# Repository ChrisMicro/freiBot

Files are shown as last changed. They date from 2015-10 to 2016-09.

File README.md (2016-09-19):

# freiBot
The freiBot is a very low cost two wheel robot.
The design goal is a robot which is
- easy and fast to build ( 6 hours )
- easy to program ( using an ARDUINO NANO )
- low circuit cost
- usefull for workshops

Here you can see the pictures:

http://roboterclub-freiburg.de/projekte/freibot

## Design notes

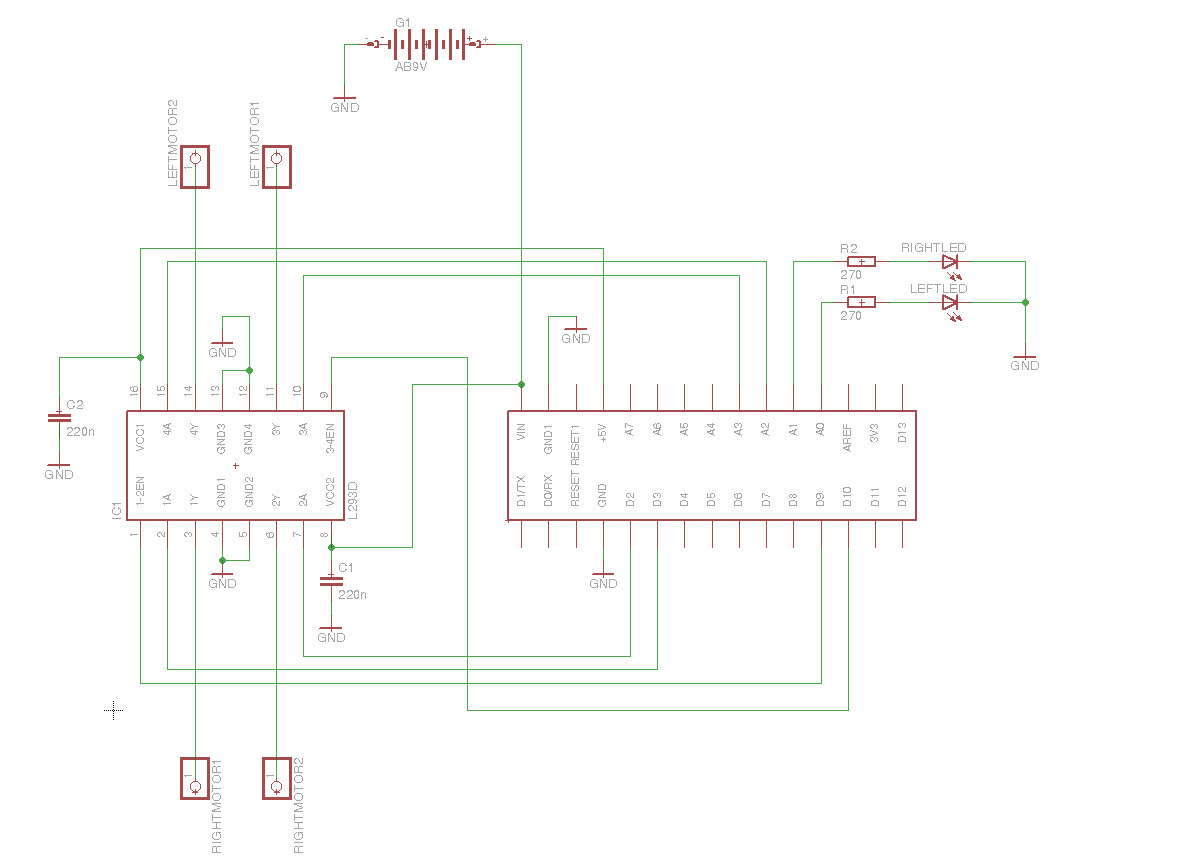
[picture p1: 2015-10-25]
freiBot_schnematic.jpg

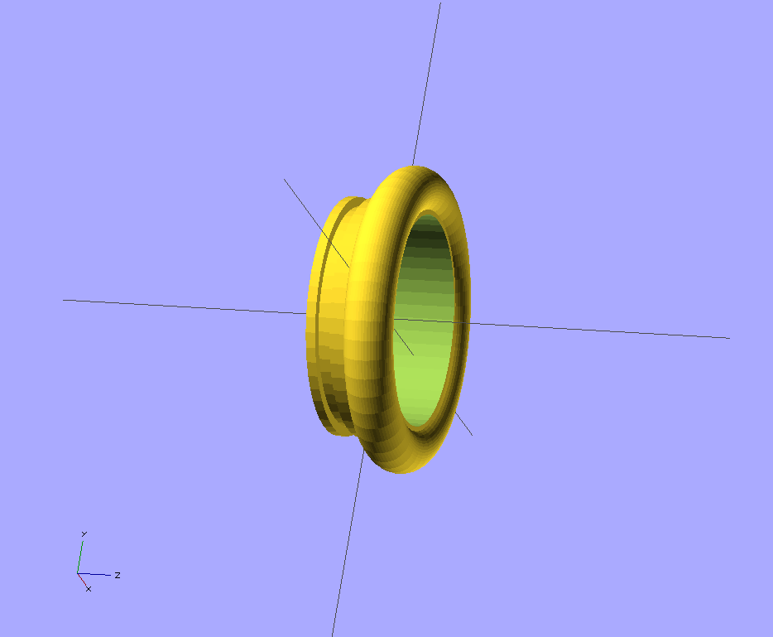
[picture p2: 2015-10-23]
cad/openscad/chFreiBotWheel.png

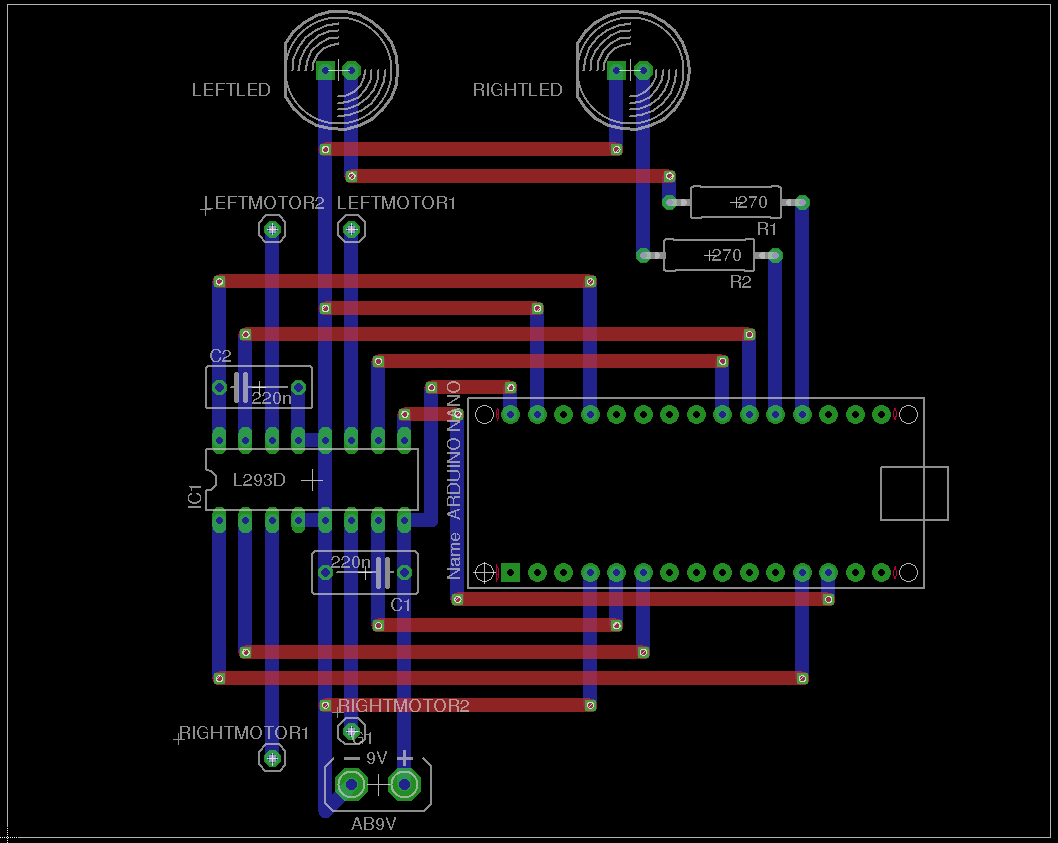
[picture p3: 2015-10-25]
eagle/StreifenrasterLayoutFreiBot20151025_1.png

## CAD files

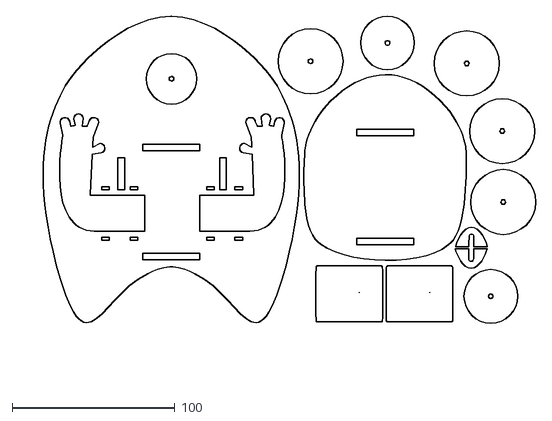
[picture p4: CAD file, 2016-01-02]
cad/freibot_grundplatte_4mm_lurch.dxf
319.6 x 224.4

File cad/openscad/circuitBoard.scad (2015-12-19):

boardLength=75;
boardHeight=1.5;
boardWidth=100;

color("silver") translate([0,0,basePlateOffset]) 		
	cube(size = [basePlateLength,basePlateWidth,basePlateHeight], center = true);

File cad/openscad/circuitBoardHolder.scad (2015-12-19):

/*
	circuit board holder

	2015 by ChrisMicro

*/

manuFactoringOffset = 1; // tollarance for colling down the PLA

// outer dimensions
frameLength = 120;
frameWidth  = 95;
frameHeight = 3;

// board dimensions
boardLength = manuFactoringOffset + 100;
boardWidth  = manuFactoringOffset + 75 ;
boardHeight = manuFactoringOffset + 1.5;

boardAuflageBreite = 3;

circuitBoardHolder();

module circuitBoardHolder()
{
	difference()
	{
		// frame
		cube([frameLength,frameWidth,frameHeight]);
	
		// hole 
		translate([(frameLength-boardLength)/2+boardAuflageBreite,(frameWidth-boardWidth)/2+boardAuflageBreite,0])
			cube([boardLength-boardAuflageBreite*2,boardWidth-boardAuflageBreite*2,frameHeight]);

		// board
		translate([(frameLength-boardLength)/2,(frameWidth-boardWidth)/2,frameHeight-boardHeight])
			cube([boardLength,boardWidth,boardHeight]);
	}
}	

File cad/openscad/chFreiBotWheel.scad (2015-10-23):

/*
	freiBot Pneu
	robot wheel for freiBot
	2015 by stochri
*/

$fn = 50;

ballBearingDiameter=22;
wheelDiameter=32;
nutBreite=1.5;
nutTiefe=2;
nutEntfernung=2;

schlauchdicke=wheelDiameter-ballBearingDiameter;

d1=1;
d2=1;

// reifen 
translate([0,0,schlauchdicke/4])
	torus(ballBearingDiameter,wheelDiameter);

// auffüllung rad reifen
translate([0,0,0])
	ring(schlauchdicke/4+d1,ballBearingDiameter,wheelDiameter-schlauchdicke/2);

// innenring der nut
translate([0,0,-nutEntfernung])
	ring(schlauchdicke/2+d1,ballBearingDiameter,ballBearingDiameter+d2+nutTiefe);

// nut für gummiantrieb
translate([0,0,-nutEntfernung-nutBreite])
	ring(nutBreite,ballBearingDiameter,ballBearingDiameter+d2);

// aussenring der nut
translate([0,0,-nutEntfernung-nutBreite-d1])
	ring(d1,ballBearingDiameter,ballBearingDiameter+d2+nutTiefe);


module ring(thickness,innerDiameter,outerDiameter)
{
	difference()
	{
		cylinder(thickness,outerDiameter/2,outerDiameter/2);
		cylinder(thickness,innerDiameter/2,innerDiameter/2);
	}	
}

module torus(inner,outer)
{
	rotate_extrude(convexity = 10)
	translate([outer/2-(outer/2-inner/2)/2, 0, 0])
		circle(r = (outer/2-inner/2)/2); 
}

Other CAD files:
cad/openscad/freiBotWheelDualRubberBand.scad
cad/openscad/BatteryHolder9V.scad
cad/openscad/JohnsonNF243G-20242.scad
cad/openscad/Main_baseplate.scad
cad/openscad/axis.scad
cad/openscad/axisBearings.scad
cad/openscad/axisBearingsDual.scad
cad/openscad/ballBearing.scad
cad/openscad/baseplate.scad
cad/openscad/freiBotWheelRubberBand.scad
cad/openscad/freiBotWheelRubberWasher.scad
cad/openscad/freiBot_pneu.scad
cad/openscad/lgo_holePlate.scad
cad/openscad/motorHolder.scad
cad/openscad/motorHolderWithOutBasePlate.scad
cad/openscad/motorHolderlgo.scad
cad/openscad/pulley.scad
cad/openscad/switchMount.scad
cad/openscad/washer.scad

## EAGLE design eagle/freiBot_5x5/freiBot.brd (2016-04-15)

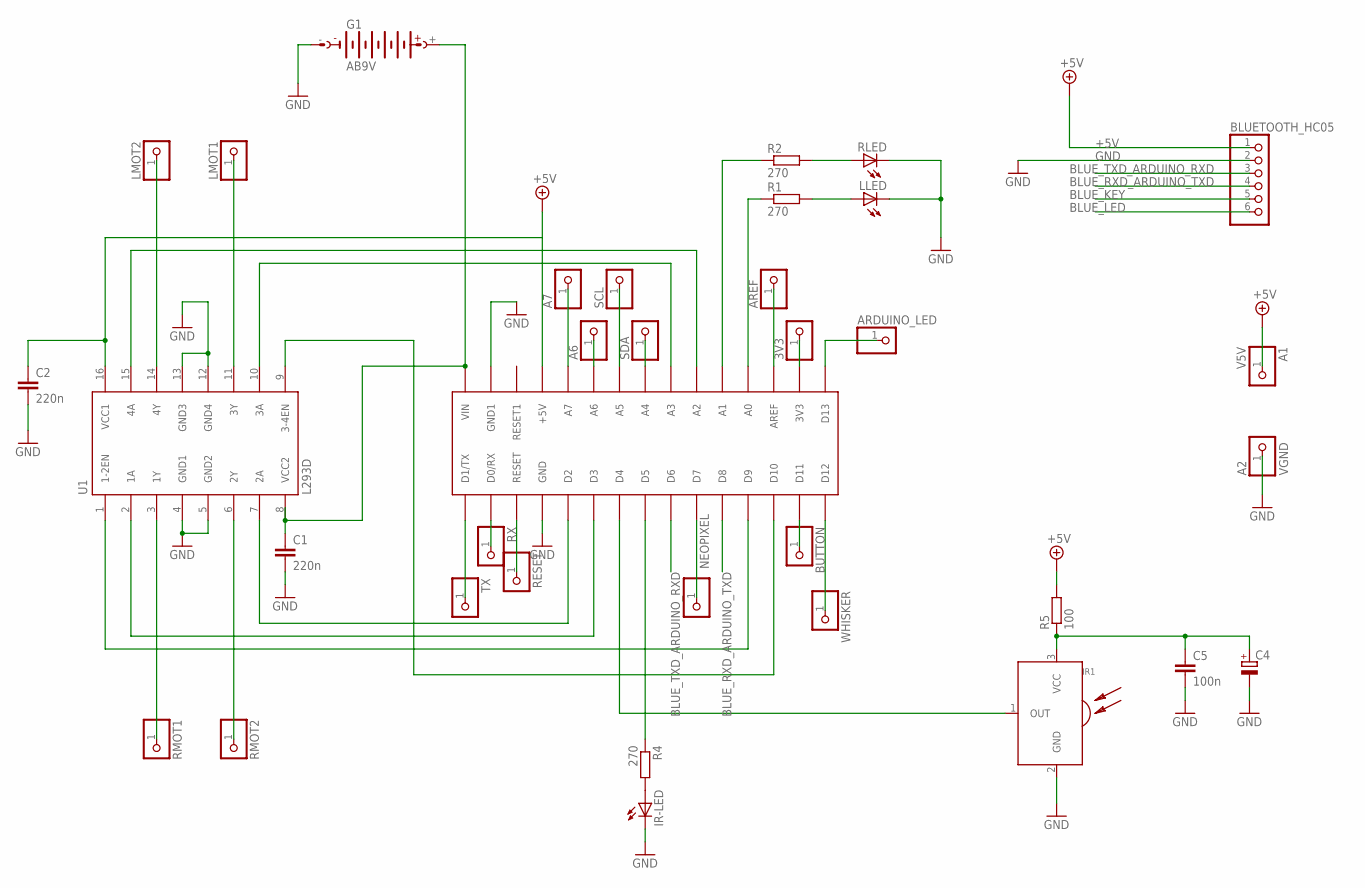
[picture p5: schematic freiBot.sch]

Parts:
3V3: PINHD-1X1; 1X01
A1: V5V; 1X01
A2: VGND; 1X01
A6, A7: PINHD-1X1; 1X01
ARDUINO_LED: PINHD-1X1; 1X01
AREF: PINHD-1X1; 1X01
BLUETOOTH_HC05: PINHD-1X6; 1X06
BUTTON: PINHD-1X1; 1X01
C1, C2: 220n; C075-042X103
C4: CPOL-EUE5-8.5; E5-8,5
C5: 100n; C050-025X075
G1: AB9V
IR1: SFH5110; SFH511*
IR-LED: LED5MM
LLED: LED10MM
LMOT1, LMOT2: PINHD-1X1; 1X01
NEOPIXEL: PINHD-1X1; 1X01
R1, R2, R4: 270; 0309/12
R5: 100; 0309/10
RESET: PINHD-1X1; 1X01
RLED: LED10MM
RMOT1, RMOT2: PINHD-1X1; 1X01
RX: PINHD-1X1; 1X01
SCL: PINHD-1X1; 1X01
SDA: PINHD-1X1; 1X01
TX: PINHD-1X1; 1X01
U1: L293D; DIL16
U2: ARDUINONANO; PDIP-32
WHISKER: PINHD-1X1; 1X01

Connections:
+5V: A1.1, BLUETOOTH_HC05.1, C2.1, R5.2, U1.16 (VCC1), U2.+5V
BLUE_KEY: BLUETOOTH_HC05.5
BLUE_LED: BLUETOOTH_HC05.6
BLUE_RXD_ARDUINO_TXD: BLUETOOTH_HC05.4, U2.D8
BLUE_TXD_ARDUINO_RXD: BLUETOOTH_HC05.3, U2.D6
GND: A2.1, BLUETOOTH_HC05.2, C1.2, C2.2, C4.-, C5.2, G1.-, IR1.2 (GND), IR-LED.K (C), LLED.K (C), RLED.K (C), U1.4 (GND1), U1.5 (GND2), U1.12 (GND4), U1.13 (GND3), U2.GND, U2.GND1
unnamed: U1.7 (2A), U2.D2
unnamed: U1.2 (1A), U2.D3
unnamed: U1.1 (1-2EN), U2.D9
unnamed: RMOT1.1, U1.3 (1Y)
unnamed: U1.9 (3-4EN), U2.D10
unnamed: U1.10 (3A), U2.A3
unnamed: U1.15 (4A), U2.A2
unnamed: RMOT2.1, U1.6 (2Y)
unnamed: LMOT1.1, U1.11 (3Y)
unnamed: LMOT2.1, U1.14 (4Y)
unnamed: C1.1, G1.+, U1.8 (VCC2), U2.VIN
unnamed: IR-LED.A, R4.2
unnamed: R1.1, U2.A0
unnamed: R2.1, U2.A1
unnamed: R2.2, RLED.A
unnamed: LLED.A, R1.2
unnamed: SDA.1, U2.A4
unnamed: SCL.1, U2.A5
unnamed: ARDUINO_LED.1, U2.D13
unnamed: U2.D12, WHISKER.1
unnamed: BUTTON.1, U2.D11
unnamed: NEOPIXEL.1, U2.D7
unnamed: IR1.1 (OUT), U2.D4
unnamed: R4.1, U2.D5
unnamed: A6.1, U2.A6
unnamed: 3V3.1, U2.3V3
unnamed: AREF.1, U2.AREF
unnamed: A7.1, U2.A7
unnamed: RESET.1, U2.RESET
unnamed: TX.1, U2.D1/TX
unnamed: RX.1, U2.D0/RX
VCC: C4.+, C5.1, IR1.3 (VCC), R5.1

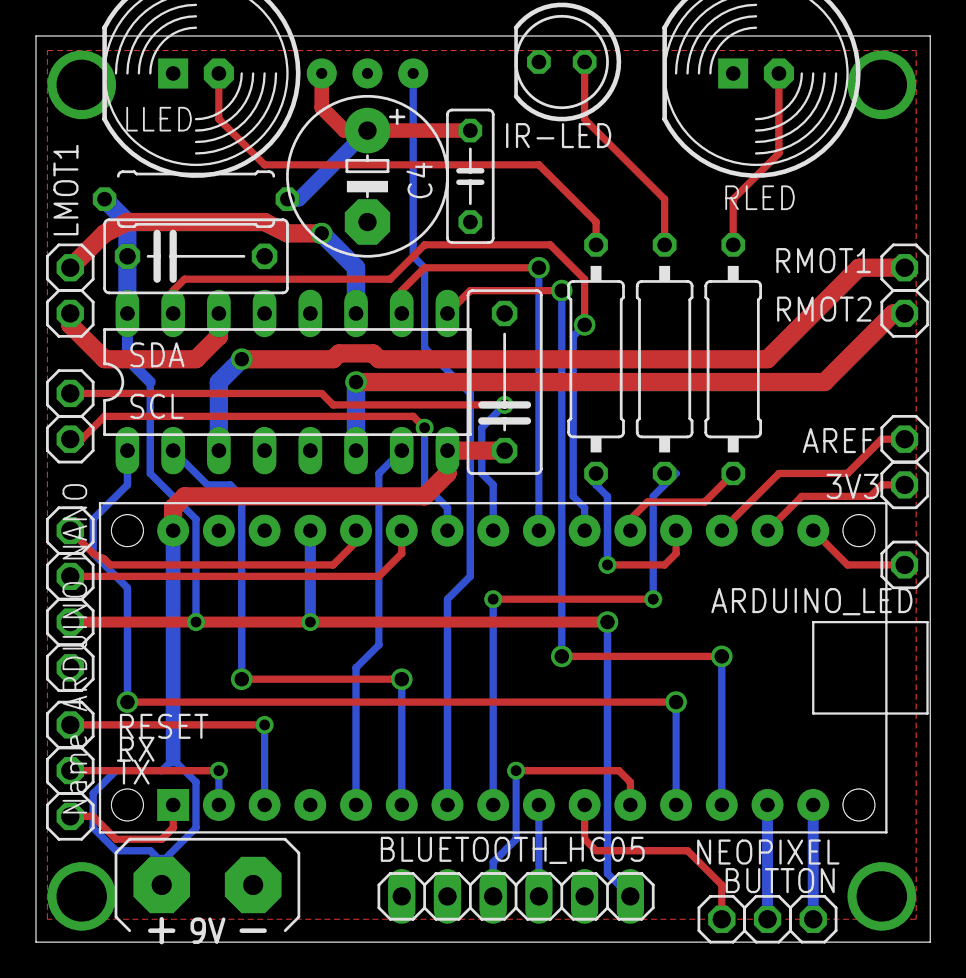
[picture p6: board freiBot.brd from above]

Board: 2 copper layers, 49.7 x 50.3 mm, 35 parts (1 on the bottom side), 36 nets.

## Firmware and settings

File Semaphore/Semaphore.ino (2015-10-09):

#include "freiBot.h"

void setup()
{
  initRobotHardware();
  Serial.begin(9600);
}



uint8_t Semaphore = 0;
// robot state machine with semaphores
void stateMachine()
{
  while (1)
  {
    Serial.print("semaphore: "); Serial.println(Semaphore);

    if ((Semaphore == FREE) || (Semaphore == 1))
    {
      Semaphore = 1;
      if (!digitalRead(BUTTONPIN))
      {
        Semaphore = FREE;
        Serial.println("button pressed");
        digitalWrite(LEDPIN, false);
      }
      else
      {
        digitalWrite(LEDPIN, true);
      }
    }

    if (whiskerTouched())
    {
      MotorDir(RWD, RWD);
      MotorSpeed(255, 100);
      digitalWrite(EYE_LED_LEFT,  0);
      digitalWrite(EYE_LED_RIGHT, 1);
    }

    if ((Semaphore == FREE) || (Semaphore == 2))
    {
      static uint32_t stopTime;
      static uint8_t stateFlag = 0;

      if (stateFlag == 0)
      {
        Semaphore = 2;
        stopTime = millis() + 1000;

        stateFlag = 1;
        MotorDir(FWD, FWD);
        MotorSpeed(255, 255);
        digitalWrite(EYE_LED_LEFT,  1);
        digitalWrite(EYE_LED_RIGHT, 1);
      } else
      {
        if (millis() > stopTime)
        {
          stateFlag = 0;
          Semaphore = FREE;
        }
      }
    }

    if ((Semaphore == FREE) || (Semaphore == 3))
    {
      static uint32_t stopTime;
      static uint8_t stateFlag = 0;

      if (stateFlag == 0)
      {
        Semaphore = 3;
        stopTime = millis() + 1000;
        stateFlag = 1;
        MotorDir(FREE, FREE);
        digitalWrite(EYE_LED_LEFT,  0);
        digitalWrite(EYE_LED_RIGHT, 0);
      } else
      {
        if (millis() > stopTime)
        {
          stateFlag = 0;
          Semaphore = 2;
        }
      }
    }
  }
}

#define MAXSPEED 230
#define MINSPEDD 1
#define SPEEDINCREMENT 10

void lightChaser()
{
  uint8_t leftSpeed = 0;
  uint8_t rightSpeed = 0;
  MotorDir(FWD, FWD);

  while (1)
  {
    MotorSpeed(leftSpeed, rightSpeed);
    if (get_eyeValue(LEFT) > get_eyeValue(RIGHT))
    {
      leftSpeed += SPEEDINCREMENT;
      rightSpeed -= SPEEDINCREMENT;

      setLed(EYE_LED_LEFT, 1);
      setLed(EYE_LED_RIGHT, 0);
      delay(10);
    }
    else
    {
      leftSpeed -= SPEEDINCREMENT;
      rightSpeed += SPEEDINCREMENT;
      setLed(EYE_LED_LEFT, 0);
      setLed(EYE_LED_RIGHT, 1);
      delay(10);
    }
    if (leftSpeed < MINSPEDD)leftSpeed = MINSPEDD;
    if (rightSpeed < MINSPEDD)rightSpeed = MINSPEDD;
    if (leftSpeed > MAXSPEED )leftSpeed = MAXSPEED ;
    if (rightSpeed > MAXSPEED )rightSpeed = MAXSPEED ;
  }
}

void testIrInput()
{
  setLed(EYE_LED_LEFT, 0);
  waitForIrSignal();
  setLed(EYE_LED_LEFT, 1);
  delay(100);
}

void simpleIrMotorControl()
{
  int n, k;
  BEEP;
  waitForIrSignal(); // wait for start signal
  MotorDir(FWD, RWD); // rotate if there is no signal
  MotorSpeed(200, 200);
  for (n = 0; n < 300; n++)
  {
    if(isIrSignal()) // if signal, go forward
    {
      setLed(EYE_LED_LEFT, 1);
      MotorDir(FWD, FWD); 
      delay(500);
      setLed(EYE_LED_LEFT, 0);
    } else 
    {
      MotorDir(FWD, RWD); // rotate if there is no signal
      delay(10);
    }
    if(whiskerTouched())
    {
      chirp();

      MotorSpeed(200, 200);
      // go back
      MotorDir(RWD, RWD); 
      delay(300);
      // turn
      MotorDir(FWD, RWD);
      delay(300);
    }
  }
  MotorDir(FREE, FREE); // turn of motor if there is no signal

}



void loop()
{
  simpleIrMotorControl();
  //testIrInput();
  /*
  lightChaser();
  Serial.print("left: "); Serial.print(get_eyeValue(LEFT));
  Serial.print("  right: "); Serial.println(get_eyeValue(RIGHT));
  delay(10);
  */
}

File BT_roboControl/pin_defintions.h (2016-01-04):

/*************************************************************************************

  GENUBOT 

  robot hardware:

  microcontroller:     Arduino Nano
  motor driver:        L293D
  motors:              Pollin motors 
  wheels:              inline skate ball bearings
  
  sensors:
  - button
  - 1 whisker 
  - 2 LEDs ( used as light sensor )
  - MPU6050 3 axis accelerometer/gyrometer 
  - IR sensor SFH5110

************************************************************************************/

// Arduino Nano pin out and schematic:
// https://www.arduino.cc/en/uploads/Main/ArduinoNanoManual23.pdf

// connecting the ARDUINO Nano and the MPU6050 accelerometer:
// http://shirotsuku.sakura.ne.jp/blog/?p=442
// ( interrupt pin is not connected at the moment to genubot )

// net list:
//===== robot pin name =  ARDUINO pin ===============================================================
#define MOTOR_RIGHT1           2 // dout, L293D pin10, motor driver right side, half bridge 1
#define MOTOR_RIGHT2           3 // dout, L293D pin15, motor driver right side, half bridge 2
#define IR_SENSOR              4  // din , SFH5110 sensor ( signal is active low )
#define BLUE_TXD_ARDUINO_RXD   6  // din, bluetooth hc05 modul 
#define NEOPIXEL_PIN           7  // dout, WS2812 RGB LED controll pin
#define BLUE_RXD_ARDUINO_TXD   8  // dout, bluetooth hc05 modul 
#define ENABLE_RIGHT           9  // dout, L293D pin1, motor driver enable pin for right motor, OC1B used for motor PWM
#define ENABLE_LEFT           10 // dout, L293D pin9, motor driver enable pin for left moter, OC1A used for motor PWM
#define BUTTONPIN             11 // din,  button ( configure with pull up )
#define WHISKERPIN            12 // din,  whisker ( like a button configure with pull up )
#define LEDPIN                13 // dout, ARDUINO NANO LED 

#define EYE_LED_LEFT     A0 // dout,ain, LED or LED as light sensor
#define EYE_LED_RIGHT    A1 // dout,ain, LED or LED as light sensor
#define MOTOR_LEFT2      A2  // dout, L293D pin2, motor driver left side half bridge 2
#define MOTOR_LEFT1      A3  // dout, L293D pin7, motor driver left side half bridge 1

// A2
// A3
#define I2C_SDA_PIN      A4 // I2C SDA, connected to MPU6050
#define I2C_SCL_PIN      A5 // I2C SCL, connected to MPU6050
// A6
// A7

// tbd:
// IR-LED digital out for distance sensor
// digital input for second whisker
// CNY70 line sensor digital out for LED
// CNY70 line sensor digital in for sensor

/*******************************************************************************
*   -c--date---version--nickname--------email---------------------------------
*
*   (c) 2015   V0.1     stochri         christoph(at)roboterclub-freiburg.de
*   (c) ..     V0.2     ...... ........ ( your name ) ........................
*
*******************************************************************************
*   This program is free software; you can redistribute it and/or modify      *
*   it under the terms of the GNU General Public License as published by      *
*   the Free Software Foundation version 2 of the License,                    *
*   If you want to use this software for commercial purposes and you          *
*   don't want to make it open source, please contact the authors for         *
*   licensing.                                                                *
*                                                                             *
*   IF YOU EXTEND THE PROGRAM PLEASE MAINTAIN THE LIST OF AUTHORS             *
*   ( which means adding copyright in the list above )                        *
*                                                                             *
*******************************************************************************/

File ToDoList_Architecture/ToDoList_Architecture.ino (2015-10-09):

/*
 ============================================================================
 Name        : ToDoBuffer_Architecture.c
 Author      : chris
 Version     :
 Copyright   : GPL V3
 Description : ToDo list architecture to control a robot
 ============================================================================
 */
#include "freiBot.h"

#include "ringBuffer.h"

#define TODOLIST_SIZE 100
ToDo_t ToDoList[TODOLIST_SIZE];

ringBuffer_t ToDoBuffer;

void Speed(int16_t a, int16_t b)
{
  MotorSpeed(a, b);
}

void Direction(int16_t a, int16_t b)
{
  MotorDir(a, b);
}

#define FORWARD_LENGTH 2
ToDo_t Forward_List[] =
{
  // turn robot
  {0, Direction, FWD, FWD},
  {500, Speed, 200, 200},
};

#define TURNLEFT_LENGTH 3
ToDo_t TurnLeft_List[] =
{
  // turn robot
  {0, Direction, FWD, RWD},
  {500, Speed, 200, 200},
  // stop motors and wait for two seconds
  {2000, Direction, FREE, FREE}
};

#define BOUNCE_BACK 4
ToDo_t BounceBack_List[] =
{
  // drive back
  {0, Direction, RWD, RWD},
  {300, Speed, 200, 200},
  // turn
  {300, Direction, FWD, RWD},
  // stop motors and wait for 200ms
  {200, Direction, FREE, FREE}
};

void bounceBackBehaviour(int16_t var1, int16_t var2)
{
  ringBufAddInFront(&ToDoBuffer, BounceBack_List, BOUNCE_BACK);
}

void rotateBehaviour(int16_t var1, int16_t var2)
{
  ringBufAddInFront(&ToDoBuffer, TurnLeft_List, TURNLEFT_LENGTH);
}

void forwardBehaviour(int16_t var1, int16_t var2)
{
  ringBufAddInFront(&ToDoBuffer, Forward_List, FORWARD_LENGTH);
}

void setup()
{
  initRobotHardware();
  Serial.begin(9600);
  ringBufferInit( &ToDoBuffer, ToDoList, TODOLIST_SIZE  );

  ringBufAddInFront(&ToDoBuffer, TurnLeft_List, TURNLEFT_LENGTH);
  bounceBackBehaviour(0, 0);
  ringBufAddInFront(&ToDoBuffer, TurnLeft_List, TURNLEFT_LENGTH);
}

void simpleIrMotorControl()
{
  int n, k;
  beep();
  waitForIrSignal(); // wait for start signal
  MotorDir(FWD, RWD); // rotate if there is no signal
  MotorSpeed(200, 200);
  for (n = 0; n < 300; n++)
  {
    if (isIrSignal()) // if signal, go forward
    {
      setLed(EYE_LED_LEFT, 1);
      MotorDir(FWD, FWD);
      delay(500);
      setLed(EYE_LED_LEFT, 0);
    } else
    {
      MotorDir(FWD, RWD); // rotate if there is no signal
      delay(10);
    }
    if (whiskerTouched())
    {
      chirp();

      MotorSpeed(200, 200);
      // go back
      MotorDir(RWD, RWD);
      delay(300);
      // turn
      MotorDir(FWD, RWD);
      delay(300);
    }
  }
  MotorDir(FREE, FREE); // turn of motor if there is no signal

}

uint32_t NextTime = 0;

void whiskerTest()
{
  if (whiskerTouched())
  {
    setLed(EYE_LED_LEFT, 1);

    delay(1);

  } else setLed(EYE_LED_LEFT, 0);
}

void loop()
{
  ToDo_t action;

  if (millis() > NextTime) // check if the next action has to be taken
  {
    if ( ! ringBufferIsEmpty(&ToDoBuffer) )
    {
      action = ringBufGetValue( &ToDoBuffer);
      action.DoFunction(action.var1, action.var2);

      NextTime = millis() + action.runTime;

      printf("size:%d: ", ringBufGetFillSize(&ToDoBuffer));
    }
  }

  // sensor activations
  if( whiskerTouched() ) bounceBackBehaviour(0, 0);
  //if( isIrSignal()     ) forwardBehaviour(0,0);
}

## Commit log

2015-08-28 eye leds added
2015-08-29 eye leds as light sensor
2015-08-29 accelaration sensor test added
2015-09-11 ir sensor added
2015-09-19 motor examples added
2015-10-02 motor pins corrected
2015-10-09 pins corrected in TEST_motor_lowestLevel
    [Example_ToneMelody.ino, TEST_motor.ino, TEST_motor_lowestLevel.ino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]
2015-10-09 schematic added
2015-10-17 motor free corrected in EXPERIMENTAL_sidewalk
    [asuro.cpp]
2015-10-17 wait for light beep corrected
    [Example_waitForLight.ino, asuro.cpp, freiBot.cpp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]
2015-10-18 line follow not working yet
    [EXPERIMENTAL_lineFollow.ino, asuro.cpp, asuro.h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]
2015-10-23 openscad design files added
    [axis.scad, chFreiBotWheel.scad]
2015-10-23 ball bearing dimensions added
    [ballBearing.scad]
2015-10-25 eagle schematic added
    [baseplate.scad, freiBot.brd, freiBot.sch]
2015-10-28 SGMK pneu added
    [freiBot_pneu.scad]
2015-12-16 freibot_pnew now with hub. It does not need a ball bearing any more
    [freiBot_pneu.scad, washer.scad]
2015-12-17 motor model added
    [JohnsonNF243G-20242.scad]
2015-12-18 motor holder added
    [JohnsonNF243G-20242.scad, motorHolder.scad]
2015-12-19 circuit board holder added
    [JohnsonNF243G-20242.scad, circuitBoard.scad, circuitBoardHolder.scad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]
2015-12-19 axis bearings added
    [axisBearings.scad]
2015-12-19 main base plate with all components added
    [Main_baseplate.scad, axisBearings.scad, circuitBoardHolder.scad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]
2015-12-19 front size minimized, it was to big to print
    [Main_baseplate.scad]
2015-12-20 freibot rubber band wheel added
    [freiBotWheelRubberBand.scad, pulley.scad]
2015-12-21 fitting of motor holder improved, dual bearing base plate added
    [JohnsonNF243G-20242.scad, axisBearingsDual.scad, lgo_holePlate.scad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]
2015-12-24 new eagle schematic
    [freiBot.brd, freiBot.sch]
2015-12-25 additional parts added
    [BatteryHolder9V.scad, freiBotWheelDualRubberBand.scad, motorHolderWithOutBasePlate.scad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]
2015-12-29 light sensor graph with less swing
    [lgo_holePlate.scad]
2015-12-30 fast adc sample added
2015-12-31 light sensor detection improved
2016-01-02 grundplatte lurch from cholinska added
    [BatteryHolder9V.scad, JohnsonNF243G-20242.scad, Main_baseplate.scad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]
2016-01-04 bluetooth modul hc05 connection added
    [freiBot.brd, freiBot.sch]
2016-01-10 additional pins in schematic added
    [freiBot.brd, freiBot.sch]
2016-01-10 manually routed pcb for manual etching added
    [freiBot.brd, freiBot.sch]
2016-04-15 Alejandro's 5x5 board
    [freiBot.brd, freiBot.sch]
2017-12-03 random and sine servo added
2017-12-04 two speed servo added
